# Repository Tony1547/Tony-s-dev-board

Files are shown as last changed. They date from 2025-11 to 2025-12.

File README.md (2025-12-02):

# Tony's-dev-board
Following the dev-board tutorial & adding an awesome case (that can be put on a keychain)







CAD: https://cad.onshape.com/documents/c5034cab5a6af16967bc6f77/w/0904c445d2f2abc194a185dd/e/55b6160e95263006e3b240b2 (also in the files)

BOM: https://docs.google.com/spreadsheets/d/1fPphZmWIDkRLiHGIMIhjy6UCU6EgHhpaO0yYP-10utQ/edit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 (also in the files)

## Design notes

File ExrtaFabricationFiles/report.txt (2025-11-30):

Warning: Width correction constrained.  The width correction value must be in the range of [0.000001 mm; 0.199999 mm] for the current design rules.
Plotted to '/home/tony/Documents/Tony's devboard/Tony's devboard-F_Cu.gbr'.
Plotted to '/home/tony/Documents/Tony's devboard/Tony's devboard-B_Cu.gbr'.
Plotted to '/home/tony/Documents/Tony's devboard/Tony's devboard-F_Adhesive.gbr'.
Plotted to '/home/tony/Documents/Tony's devboard/Tony's devboard-B_Adhesive.gbr'.
Plotted to '/home/tony/Documents/Tony's devboard/Tony's devboard-F_Paste.gbr'.
Plotted to '/home/tony/Documents/Tony's devboard/Tony's devboard-B_Paste.gbr'.
Plotted to '/home/tony/Documents/Tony's devboard/Tony's devboard-F_Silkscreen.gbr'.
Plotted to '/home/tony/Documents/Tony's devboard/Tony's devboard-B_Silkscreen.gbr'.
Plotted to '/home/tony/Documents/Tony's devboard/Tony's devboard-F_Mask.gbr'.
Plotted to '/home/tony/Documents/Tony's devboard/Tony's devboard-B_Mask.gbr'.
Plotted to '/home/tony/Documents/Tony's devboard/Tony's devboard-Edge_Cuts.gbr'.
Created Gerber job file '/home/tony/Documents/Tony's devboard/Tony's devboard-job.gbrjob'.
Info: Done.
Info: Done.

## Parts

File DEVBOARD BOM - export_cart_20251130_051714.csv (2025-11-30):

Index | LCSC# | MPN | Manufacturer | Package | Customer # | Description | RoHS | Quantity | MOQ | Multiple | Unit Price($) | Extended Price($) | Product Link
1 | C165948 | TYPE-C-31-M-12 | Korean Hroparts Elec | SMD |  | 1 16P Type-C SMD USB, DVI, HDMI Connector Assemblies RoHS | yes | 5 | 5 | 5 | 0.1752 | 0.88 | https://www.lcsc.com/product-detail/C165948.html
2 | C48579737 | 1812X7R105K251NT | AIDE CAPACITOR | 1812 |  | 250V 1uF X7R ±10% 1812 Ceramic Capacitors RoHS | yes | 5 | 5 | 5 | 0.1084 | 0.54 | https://www.lcsc.com/product-detail/C48579737.html
3 | C42431804 | PH2.54-1X20P-H25 | JXTCONN | Through Hole,P=2.54mm |  | 20P 1x20P Gold Brass -40℃~+105℃ Pin Header Black 2.54mm 2.5mm 6mm 3mm 3A 1 Through Hole Through Hole,P=2.54mm Headers, Male Pins RoHS | yes | 5 | 5 | 5 | 0.0342 | 0.17 | https://www.lcsc.com/product-detail/C42431804.html
4 | C49326814 | 1210X7R106K350NT | AIDE CAPACITOR | 1210 |  | 35V 10uF X7R ±10% 1210 Ceramic Capacitors RoHS | yes | 5 | 5 | 5 | 0.1711 | 0.86 | https://www.lcsc.com/product-detail/C49326814.html
5 | C48579666 | 1206C0G330J102NT | AIDE CAPACITOR | 1206 |  | 1kV 33pF C0G ±5% 1206 Ceramic Capacitors RoHS | yes | 50 | 50 | 50 | 0.013 | 0.65 | https://www.lcsc.com/product-detail/C48579666.html
6 | C20546 | NCP1117STAT3G | onsemi | SOT-223 |  | 73dB@(120Hz) Positive Adjustable 1.25V~18.8V SOT-223 Voltage Regulators - Linear, Low Drop Out (LDO) Regulators RoHS | yes | 5 | 5 | 5 | 0.2958 | 1.48 | https://www.lcsc.com/product-detail/C20546.html
7 | C49326811 | 1210X7R104K631NT | AIDE CAPACITOR | 1210 |  | 630V 100nF X7R ±10% 1210 Ceramic Capacitors RoHS | yes | 20 | 10 | 10 | 0.0705 | 1.41 | https://www.lcsc.com/product-detail/C49326811.html
8 | C17902 | 1206W4F1002T5E | UNI-ROYAL | 1206 |  | 10kΩ 250mW 200V ±100ppm/℃ Thick Film Resistor ±1% 1206 Chip Resistor - Surface Mount RoHS | yes | 100 | 100 | 100 | 0.0031 | 0.31 | https://www.lcsc.com/product-detail/C17902.html
9 | C52016391 | HX PH254-01-03-Z-L11.5 pcb pin header | hanxia | Through Hole,P=2.54mm |  | 3P 1x3P Gold Brass -40℃~+105℃ Pin Header 2.54mm 2.5mm 6mm 1kV 3mm 3A 1 Through Hole Through Hole,P=2.54mm Headers, Male Pins RoHS | yes | 20 | 20 | 20 | 0.0046 | 0.09 | https://www.lcsc.com/product-detail/C52016391.html
10 | C21190 | 0603WAF1001T5E | UNI-ROYAL | 603 |  | 100mW 1kΩ 75V ±100ppm/℃ Thick Film Resistor ±1% 0603 Chip Resistor - Surface Mount RoHS | yes | 100 | 100 | 100 | 0.001 | 0.1 | https://www.lcsc.com/product-detail/C21190.html
11 | C7450623 | GT-TC060A-H025-L1S | G-Switch | SMD,6x3mm |  | Without Bracket 6.05mm 12V 3.5mm Rectangular Button No SPST 50mA SMD,6x3mm Tactile Switches RoHS | yes | 5 | 5 | 5 | 0.0883 | 0.44 | https://www.lcsc.com/product-detail/C7450623.html
12 | C2040 | RP2040 | Raspberry Pi | LQFN-56(7x7) |  | 133MHz 30 LQFN-56(7x7) Microcontrollers RoHS | yes | 1 | 1 | 1 | 0.9482 | 0.95 | https://www.lcsc.com/product-detail/C2040.html
13 | C2907509 | FRC1206J512 TS | FOJAN | 1206 |  | 250mW 5.1kΩ 200V ±100ppm/℃ Thick Film Resistor ±5% 1206 Chip Resistor - Surface Mount RoHS | yes | 100 | 100 | 100 | 0.002 | 0.2 | https://www.lcsc.com/product-detail/C2907509.html
14 | C9002 | X322512MSB4SI | YXC Crystal Oscillators | SMD3225-4P |  | Crystal Oscillator 20pF SMD3225-4P Crystals RoHS | yes | 10 | 10 | 10 | 0.0669 | 0.67 | https://www.lcsc.com/product-detail/C9002.html
15 | C97521 | W25Q128JVSIQ | Winbond | SOIC-8-208mil |  | 128Mbit 2.7V~3.6V 133MHz SPI SOIC-8-208mil Memory (ICs) RoHS | yes | 1 | 1 | 1 | 1.8042 | 1.8 | https://www.lcsc.com/product-detail/C97521.html
16 | C2933656 | FRC1206F27R0TS | FOJAN | 1206 |  | 250mW 27Ω 200V ±100ppm/℃ Thick Film Resistor ±1% 1206 Chip Resistor - Surface Mount RoHS | yes | 100 | 100 | 100 | 0.0028 | 0.28 | https://www.lcsc.com/product-detail/C2933656.html
17 |  | PCB |  |  |  | main DEVBOARD PCB |  | 5 |  |  | 3.616 | 18.08 | https://github.com/Tony1547/Tony-s-dev-board
18 |  | 3D-Printed Parts |  |  |  | Parts to cover up PCB |  |  |  |  |  |  | https://cad.onshape.com/documents/c5034cab5a6af16967bc6f77/w/0904c445d2f2abc194a185dd/e/55b6160e95263006e3b240b2

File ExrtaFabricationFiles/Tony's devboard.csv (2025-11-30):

Id | Designator | Footprint | Quantity | Designation | Supplier and ref
1 | C10,C9 | C_0201_0603Metric_Pad0.64x0.40mm_HandSolder | 2 | 1uf
2 | J4,J3 | Molex_SL_171971-0020_1x20_P2.54mm_Vertical | 2 | Conn_01x20
3 | C14,C13 | C_0201_0603Metric_Pad0.64x0.40mm_HandSolder | 2 | 10uf
4 | C15,C16 | C_0201_0603Metric_Pad0.64x0.40mm_HandSolder | 2 | 33pF
5 | U2 | SOT-223-3_TabPin2 | 1 | NCP1117-3.3_SOT223
6 | C12,C3,C4,C8,C5,C1,C6,C17,C2,C11,C7 | C_0201_0603Metric_Pad0.64x0.40mm_HandSolder | 11 | 0.1uf
7 | R3,R4 | R_0201_0603Metric_Pad0.64x0.40mm_HandSolder | 2 | 27
8 | J1 | USB_C_Receptacle_GCT_USB4105-xx-A_16P_TopMnt_Horizontal | 1 | USB_C_Receptacle_USB2.0_14P
9 | R7 | R_0201_0603Metric_Pad0.64x0.40mm_HandSolder | 1 | 10k
10 | J2 | PinHeader_1x03_P2.54mm_Vertical | 1 | Conn_01x03
11 | R6,R5 | R_0201_0603Metric_Pad0.64x0.40mm_HandSolder | 2 | 1k
12 | SW1 | SW_PUSH_1P1T_6x3.5mm_H5.0_APEM_MJTP1250 | 1 | SW_Push
13 | U1 | QFN-56-1EP_7x7mm_P0.4mm_EP3.2x3.2mm | 1 | RP2040
14 | R2,R1 | R_0201_0603Metric_Pad0.64x0.40mm_HandSolder | 2 | 5.1k
15 | Y1 | Crystal_SMD_0603-4Pin_6.0x3.5mm_HandSoldering | 1 | Crystal_GND24
16 | U3 | SOIC-8_5.3x5.3mm_P1.27mm | 1 | W25Q128JVS

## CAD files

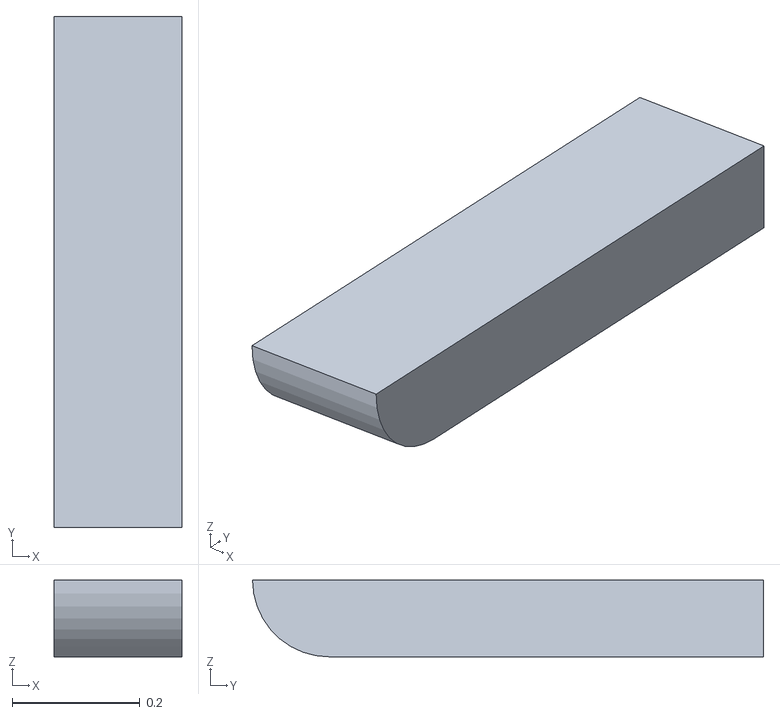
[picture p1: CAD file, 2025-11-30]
CAD/Tony's devboard 1/Tony's devboard 1 - USB_C_Receptacle_GCT_USB4105-xx-A_16P_TopMnt_Horizontal (32).stl
0.2 x 0.8 x 0.12

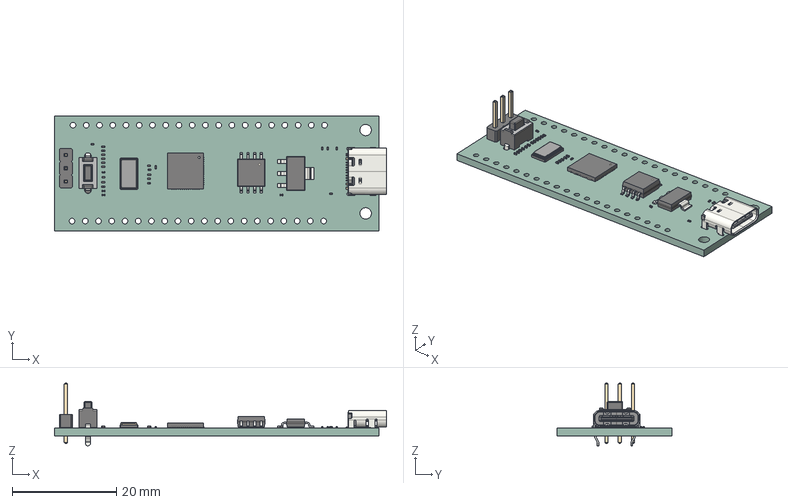
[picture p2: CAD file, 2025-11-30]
ExrtaFabricationFiles/Tony's devboard.step
63.7 x 22.0 x 12.0 mm
C_0201_0603Metric x 17
SOT-223
R_0201_0603Metric x 7
USB_C_Receptacle_GCT_USB4105-xx-A_16P_TopMnt_Horizontal
PinHeader_1x03_P2.54mm_Vertical
SW_PUSH_1P1T_6x3.5mm_H5.0_APEM_MJTP1250
QFN-56-1EP_7x7mm_P0.4mm_EP3.2x3.2mm
Crystal_SMD_0603-4Pin_6.0x3.5mm
SOIC-8_5.3x5.3mm_P1.27mm
Tony's devboard_PCB

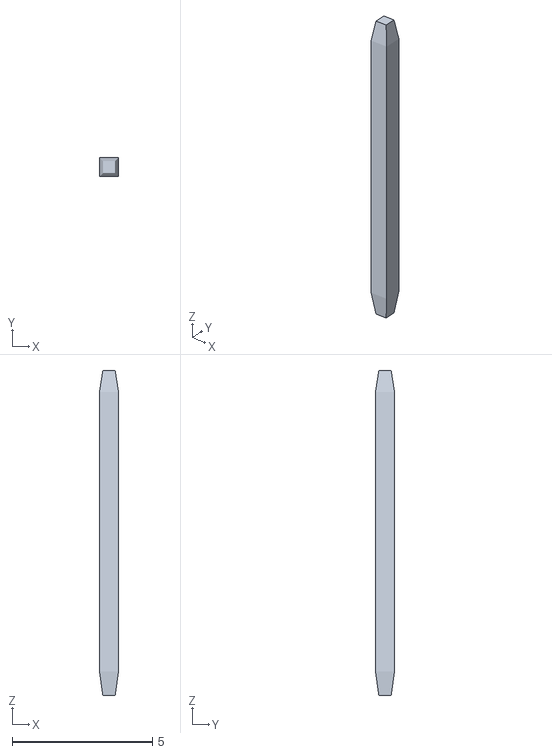
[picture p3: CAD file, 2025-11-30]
CAD/Tony's devboard 1/Tony's devboard 1 - pins 21-40 (11).stl
0.68 x 0.68 x 11.6

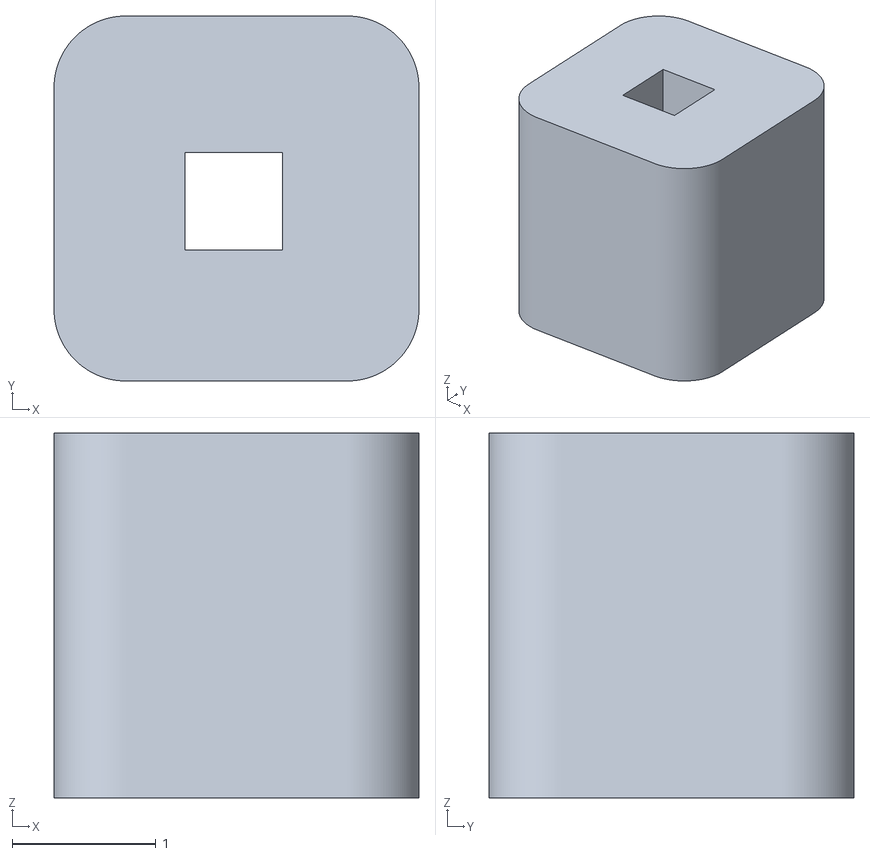
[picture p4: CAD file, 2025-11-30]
CAD/Tony's devboard 1/Tony's devboard 1 - spacer (36).stl
2.54 x 2.54 x 2.54

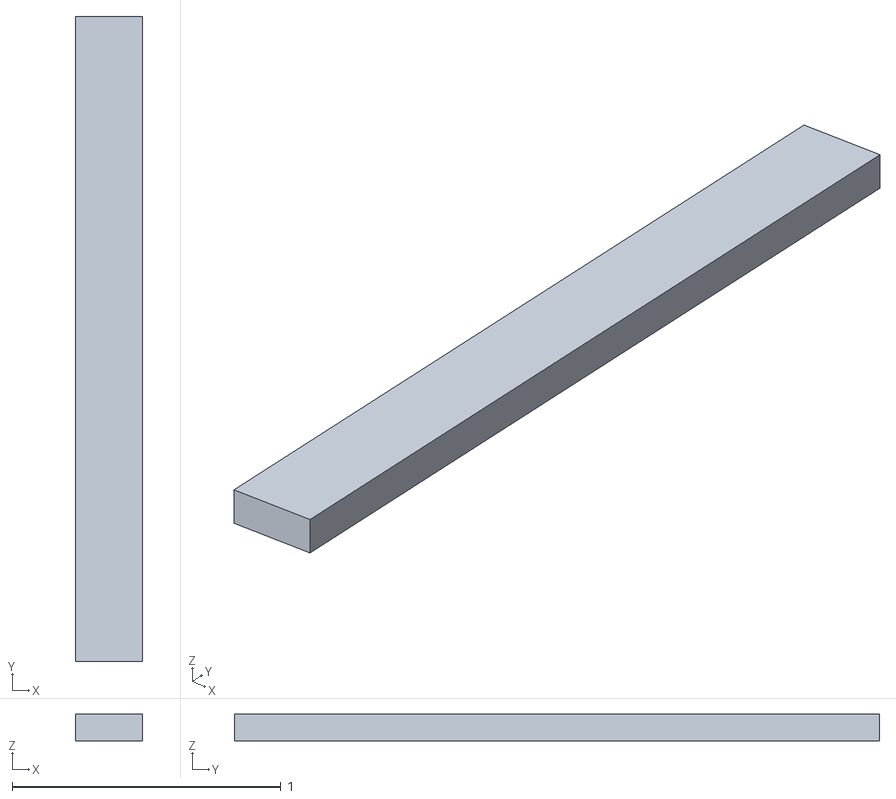
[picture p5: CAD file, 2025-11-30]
CAD/Tony's devboard 1/Tony's devboard 1 - USB_C_Receptacle_GCT_USB4105-xx-A_16P_TopMnt_Horizontal (11).stl
0.25 x 2.40 x 0.1

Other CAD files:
CAD/Tony's devboard 1/Tony's devboard 1 - pins 1-20 (14).stl
CAD/Tony's devboard 1/Tony's devboard 1 - USB_C_Receptacle_GCT_USB4105-xx-A_16P_TopMnt_Horizontal (15).stl
CAD/Tony's devboard 1/Tony's devboard 1 - pins 21-40.stl
CAD/Tony's devboard 1/Tony's devboard 1 - pins 21-40 (15).stl
CAD/Tony's devboard 1/Tony's devboard 1 - pins 21-40 (17).stl
CAD/Tony's devboard 1/Tony's devboard 1 - spacer (23).stl
CAD/Tony's devboard 1/Tony's devboard 1 - spacer (22).stl
CAD/Tony's devboard 1/Tony's devboard 1 - spacer (39).stl
CAD/Tony's devboard 1/Tony's devboard 1 - spacer (12).stl
CAD/Tony's devboard 1/Tony's devboard 1 - spacer (26).stl
CAD/Tony's devboard 1/Tony's devboard 1 - pins 1-20 (11).stl
CAD/Tony's devboard 1/Tony's devboard 1 - spacer (10).stl
CAD/Tony's devboard 1/Tony's devboard 1 - spacer (13).stl
CAD/Tony's devboard 1/Tony's devboard 1 - C_0201_0603Metric.stl
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

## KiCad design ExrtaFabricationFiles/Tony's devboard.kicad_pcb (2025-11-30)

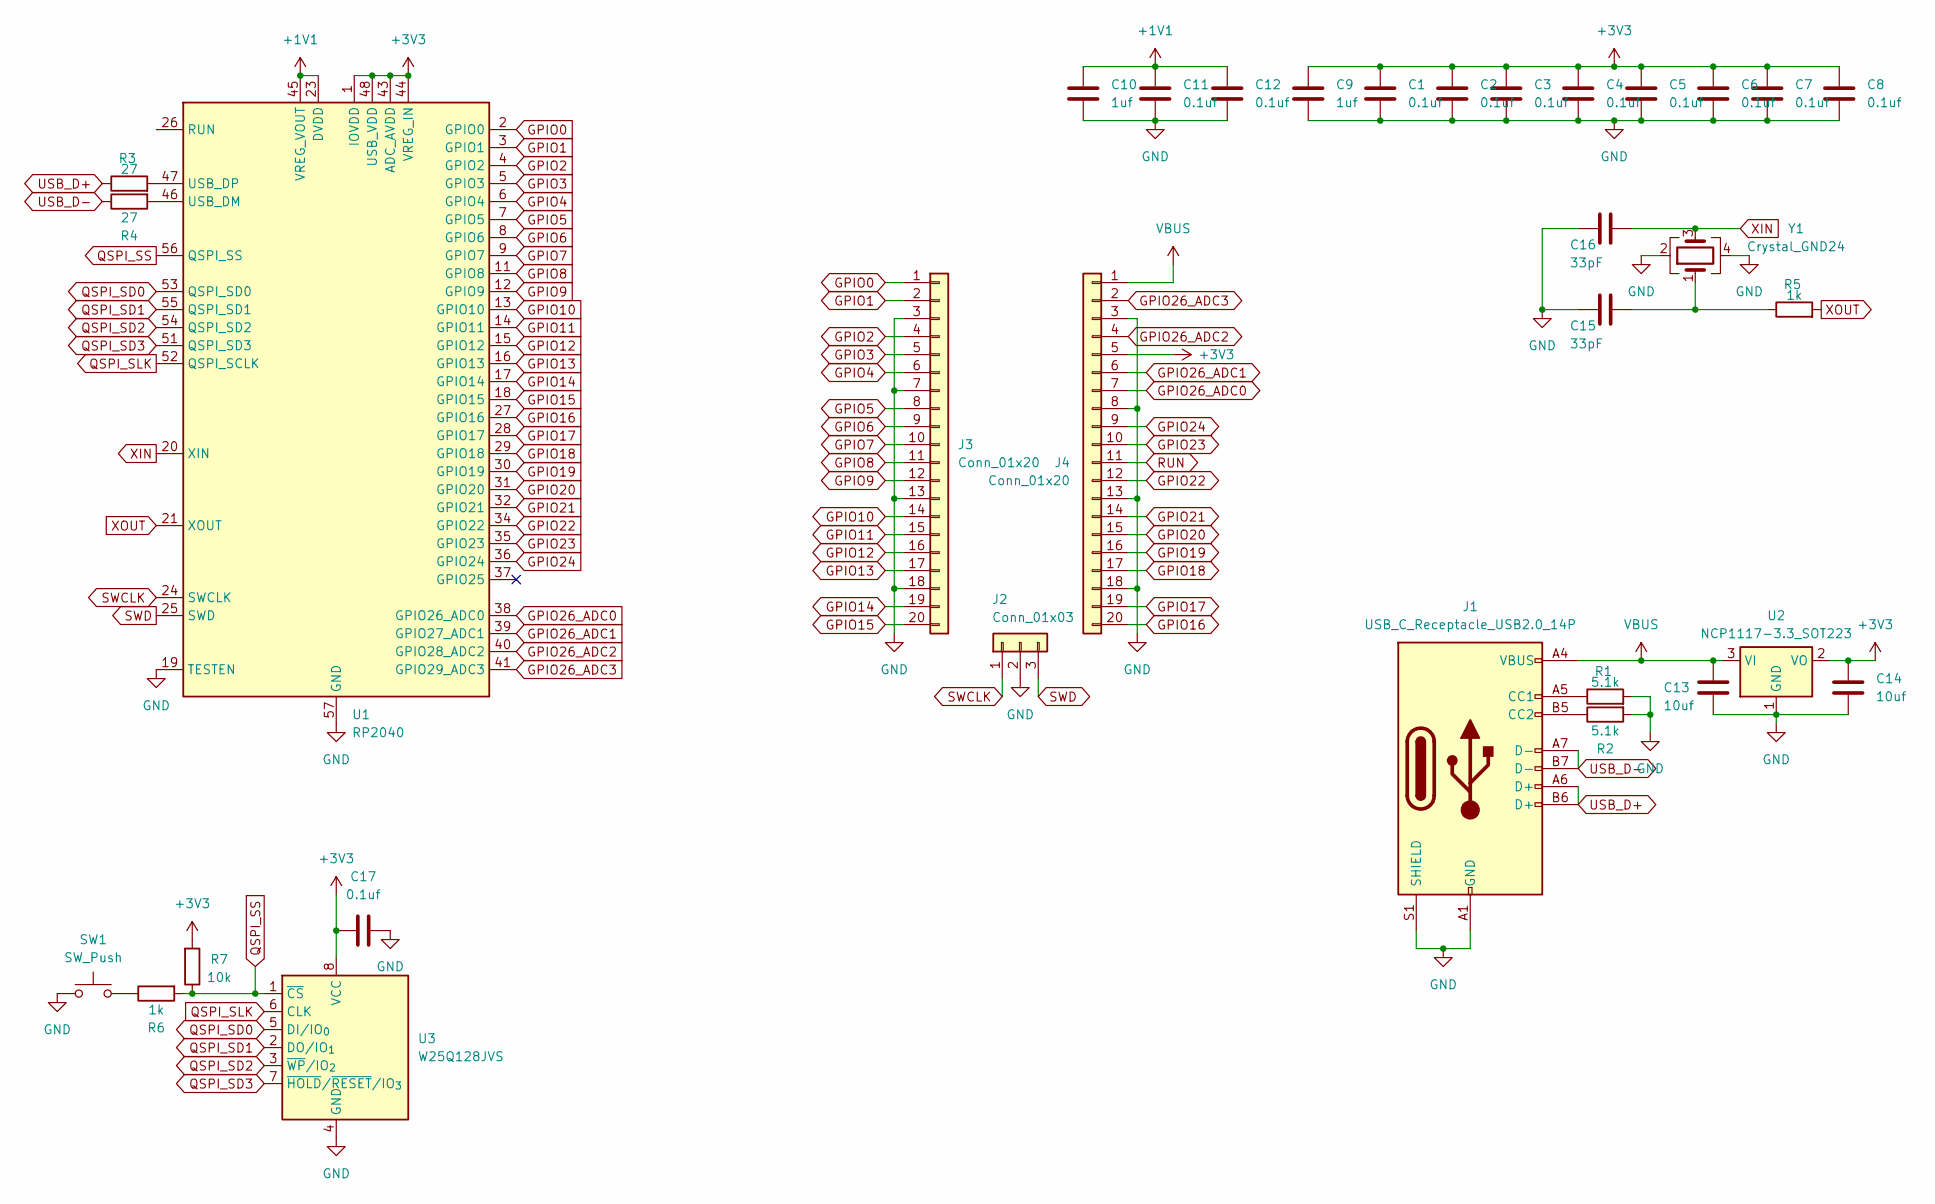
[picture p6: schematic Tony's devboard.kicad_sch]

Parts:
C1, C2, C3, C4, C5, C6, C7, C8, C11, C12, C17: 0.1uf; C_0201_0603Metric_Pad0.64x0.40mm_HandSolder
C9, C10: 1uf; C_0201_0603Metric_Pad0.64x0.40mm_HandSolder
C13, C14: 10uf; C_0201_0603Metric_Pad0.64x0.40mm_HandSolder
C15, C16: 33pF; C_0201_0603Metric_Pad0.64x0.40mm_HandSolder
J1: USB_C_Receptacle_USB2.0_14P; USB_C_Receptacle_GCT_USB4105-xx-A_16P_TopMnt_Horizontal
J2: Conn_01x03; PinHeader_1x03_P2.54mm_Vertical; Part Number 1-0301FBV0T
J3, J4: Conn_01x20; Molex_SL_171971-0020_1x20_P2.54mm_Vertical
R1, R2: 5.1k; R_0201_0603Metric_Pad0.64x0.40mm_HandSolder
R3, R4: 27; R_0201_0603Metric_Pad0.64x0.40mm_HandSolder
R5, R6: 1k; R_0201_0603Metric_Pad0.64x0.40mm_HandSolder
R7: 10k; R_0201_0603Metric_Pad0.64x0.40mm_HandSolder
SW1: SW_Push; SW_PUSH_1P1T_6x3.5mm_H5.0_APEM_MJTP1250
U1: RP2040; QFN-56-1EP_7x7mm_P0.4mm_EP3.2x3.2mm
U2: NCP1117-3.3_SOT223; SOT-223-3_TabPin2
U3: W25Q128JVS; SOIC-8_5.3x5.3mm_P1.27mm
Y1: Crystal_GND24; Crystal_SMD_0603-4Pin_6.0x3.5mm_HandSoldering

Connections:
+1V1: C10.1, C11.1, C12.1, U1.23 (DVDD), U1.45 (VREG_VOUT), U1.50 (DVDD)
+3V3: C1.1, C2.1, C3.1, C4.1, C5.1, C6.1, C7.1, C8.1, C9.1, C14.1, C17.1, J4.5, R7.2, U1.1 (IOVDD), U1.10 (IOVDD), U1.22 (IOVDD), U1.33 (IOVDD), U1.42 (IOVDD), U1.43 (ADC_AVDD), U1.44 (VREG_IN), U1.48 (USB_VDD), U1.49 (IOVDD), U2.2 (VO), U3.8 (VCC)
GND: C1.2, C2.2, C3.2, C4.2, C5.2, C6.2, C7.2, C8.2, C9.2, C10.2, C11.2, C12.2, C13.2, C14.2, C15.1, C16.1, C17.2, J1.A1 (GND), J1.A12 (GND), J1.B1 (GND), J1.B12 (GND), J1.S1 (SHIELD), J2.2, J3.3, J3.7, J3.13, J3.18, J4.3, J4.8, J4.13, J4.18, R1.2, R2.2, SW1.1, U1.19 (TESTEN), U1.57 (GND), U2.1 (GND), U3.4 (GND), Y1.2, Y1.4
GPIO0: J3.1, U1.2 (GPIO0)
GPIO1: J3.2, U1.3 (GPIO1)
GPIO2: J3.4, U1.4 (GPIO2)
GPIO3: J3.5, U1.5 (GPIO3)
GPIO4: J3.6, U1.6 (GPIO4)
GPIO5: J3.8, U1.7 (GPIO5)
GPIO6: J3.9, U1.8 (GPIO6)
GPIO7: J3.10, U1.9 (GPIO7)
GPIO8: J3.11, U1.11 (GPIO8)
GPIO9: J3.12, U1.12 (GPIO9)
GPIO10: J3.14, U1.13 (GPIO10)
GPIO11: J3.15, U1.14 (GPIO11)
GPIO12: J3.16, U1.15 (GPIO12)
GPIO13: J3.17, U1.16 (GPIO13)
GPIO14: J3.19, U1.17 (GPIO14)
GPIO15: J3.20, U1.18 (GPIO15)
GPIO16: J4.20, U1.27 (GPIO16)
GPIO17: J4.19, U1.28 (GPIO17)
GPIO18: J4.17, U1.29 (GPIO18)
GPIO19: J4.16, U1.30 (GPIO19)
GPIO20: J4.15, U1.31 (GPIO20)
GPIO21: J4.14, U1.32 (GPIO21)
GPIO22: J4.12, U1.34 (GPIO22)
GPIO23: J4.10, U1.35 (GPIO23)
GPIO24: J4.9, U1.36 (GPIO24)
GPIO26_ADC0: J4.7, U1.38 (GPIO26_ADC0)
GPIO26_ADC1: J4.6, U1.39 (GPIO27_ADC1)
GPIO26_ADC2: J4.4, U1.40 (GPIO28_ADC2)
GPIO26_ADC3: J4.2, U1.41 (GPIO29_ADC3)
unnamed: C15.2, R5.1, Y1.1
unnamed: J1.A5 (CC1), R1.1
unnamed: J1.B5 (CC2), R2.1
unnamed: R6.1, SW1.2
unnamed: R4.2, U1.46 (USB_DM)
unnamed: R3.2, U1.47 (USB_DP)
QSPI_SD0: U1.53 (QSPI_SD0), U3.5 (DI/IO_{0})
QSPI_SD1: U1.55 (QSPI_SD1), U3.2 (DO/IO_{1})
QSPI_SD2: U1.54 (QSPI_SD2), U3.3 (~WP/IO_{2})
QSPI_SD3: U1.51 (QSPI_SD3), U3.7 (~HOLD/~RESET/IO_{3})
QSPI_SLK: U1.52 (QSPI_SCLK), U3.6 (CLK)
QSPI_SS: R6.2, R7.1, U1.56 (QSPI_SS), U3.1 (~CS)
RUN: J4.11
SWCLK: J2.1, U1.24 (SWCLK)
SWD: J2.3, U1.25 (SWD)
USB_D+: J1.A6 (D+), J1.B6 (D+), R3.1
USB_D-: J1.A7 (D-), J1.B7 (D-), R4.1
VBUS: C13.1, J1.A4 (VBUS), J1.A9 (VBUS), J1.B4 (VBUS), J1.B9 (VBUS), J4.1, U2.3 (VI)
XIN: C16.2, U1.20 (XIN), Y1.3
XOUT: R5.2, U1.21 (XOUT)

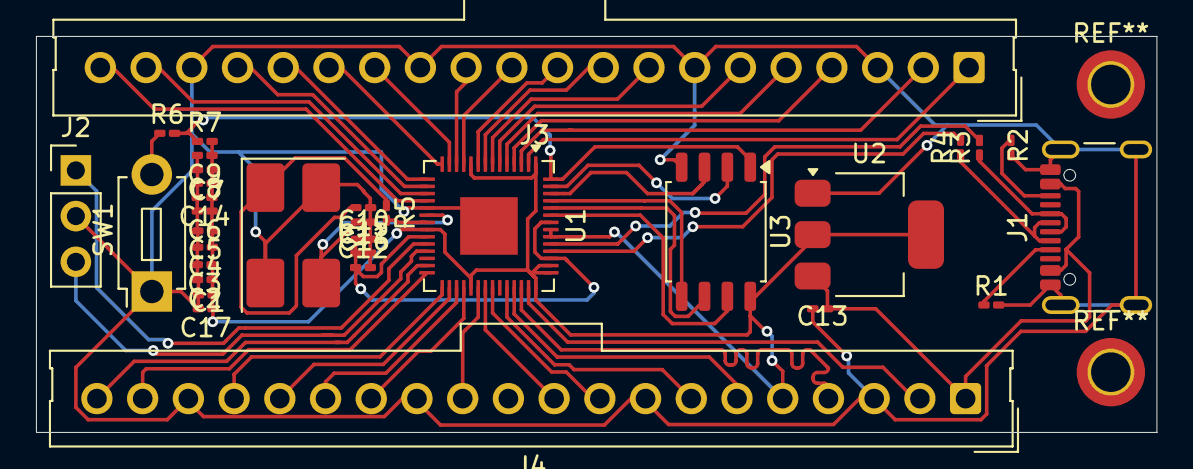
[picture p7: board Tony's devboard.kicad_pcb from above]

Board: 2 copper layers, 62.2 x 22.0 mm, 33 parts (0 on the bottom side), 51 nets.

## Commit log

2025-11-30 Extra fab files
    [DEVBOARD BOM - export_cart_20251130_051714.csv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]
2025-11-30 renamed file
    [DEVBOARD BOM - export_cart_20251130_051714.csv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]
2025-12-02 move .csv
    [Tony's devboard.csv]
2025-12-02 BOM added to front
    [DEVBOARD BOM - export_cart_20251130_051714.csv]
